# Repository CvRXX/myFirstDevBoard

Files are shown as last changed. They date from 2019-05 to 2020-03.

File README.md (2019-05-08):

# My first devboard

This devboard is meant to teach computer engineering students of the university of applied sciences to solder and to give them a learning platform to learn embeddded C++. This project is open source and can be found on github: github.com/CvRXX/myFirstDevBoard

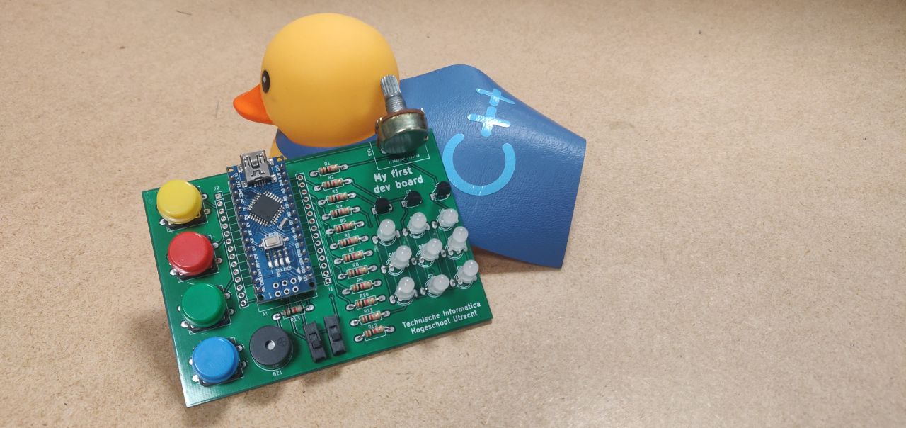
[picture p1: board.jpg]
The board


## What do you need?
To solder the board you need the following components:

    - The board (I ordered this at jlcpcb.com)
    - 13x 1kΩ resistors
    - 9x RGB LEDS (common annode)
    - 1x arduino nano with pinstrips (optionaly a female strip)
    - 1x passive buzzer
    - 4x push buttons
    - 2x slider switches (2.54mm pin distance)
    - 3x bc550 transistors 
    - 1x 1k pot meter (everything up to 10kΩ)
    - 1x usb cable for the nano
    
## How to solder it?
This readme is not a soldering course so the exact details on how to solder something should be found somewhere else. But I want to give some hints to make your life easier:

    1. Solder the components which are the lowest first (the resistors) and the highest last (the pod meter).
    2. Make sure you put in the leds the right way (long lead in the square hole).
    3. Put headers under the arduino nano so you can use the arduino for others things.
    4. Put the nano with headers on the board and then solder everything in one go.
    
## How to program it?
The one thing that I hate most about of the arduino nano is that they lack a bootloader. The students from Utrecht are lucky beause Florian and I flashed every board already. If you don't have such a nice person nearby you should flash it yourself. This tuturial describes it nicely: https://www.instructables.com/id/How-To-Burn-a-Bootloader-to-Clone-Arduino-Nano-30/.

After that you can use the arduino IDE to flash the board. The students from Utrecht are required to use bmptk & hwlib. 

To find out what is connected to what please read the schematic that's included. You can open this with the free opensource program called kicad (http://kicad-pcb.org/).

## I still run into problems, what now?
If you are a student from Utrecht you can go into the turing lab and ask Carlos, Florian or Wouter. If Utrecht is a bit far away from you feel free to email me : myfirstdevboard {at} carlosvanrooijen.nl

## I'm a teacher at an university and I really want to use this, can I?
Sure, love to see my board being used in other places. The only thing that I ask of you is that you retain my name on the board and send me an email that you use it. I only ask for the email because it makes me happy to know that others use it.

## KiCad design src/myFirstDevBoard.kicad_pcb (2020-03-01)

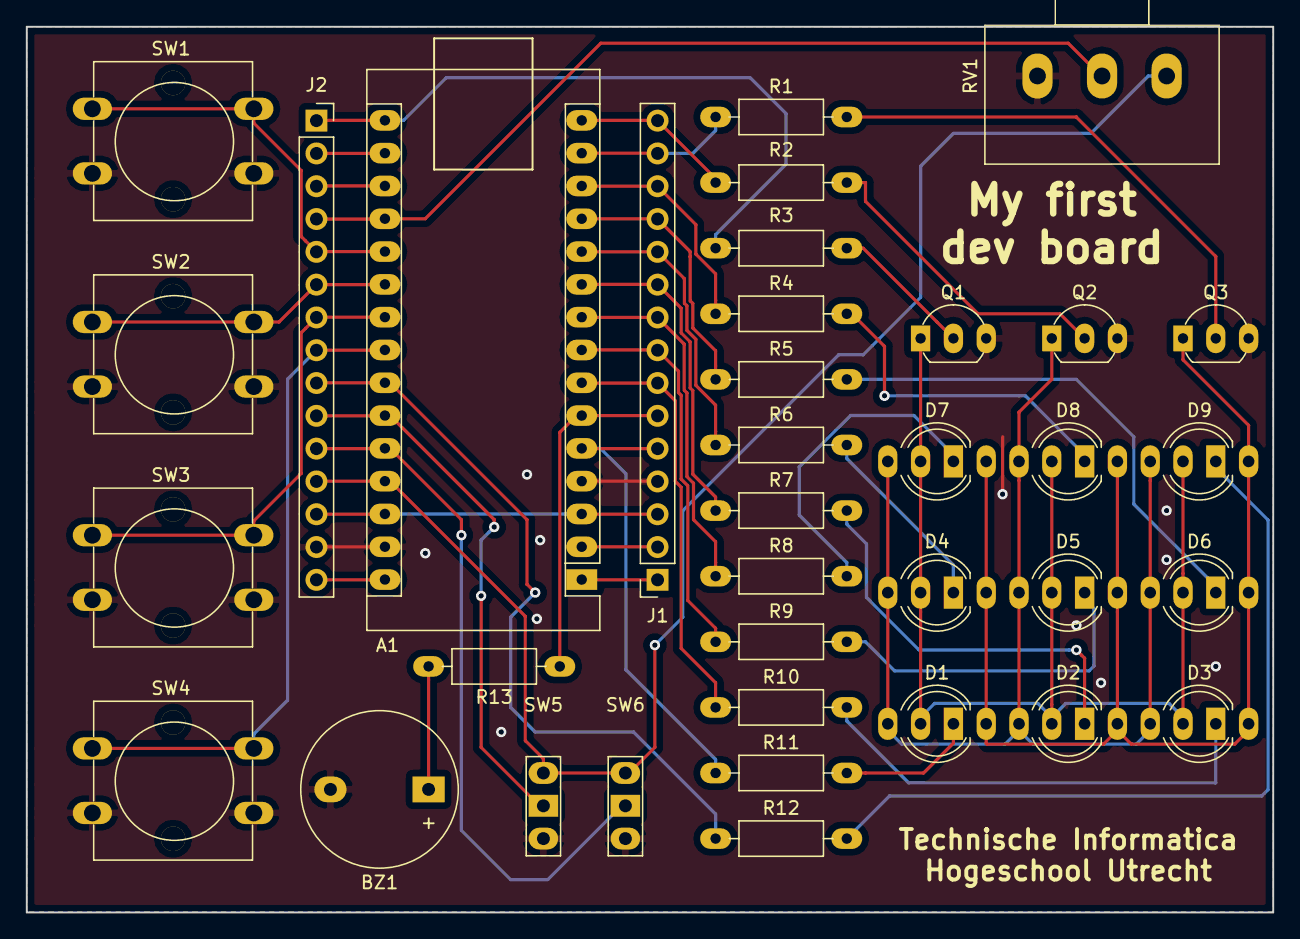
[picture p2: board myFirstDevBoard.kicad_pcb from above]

Board: 2 copper layers, 96.5 x 68.6 mm, 36 parts (0 on the bottom side), 44 nets.

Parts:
A1: Arduino_Nano_v3.x; Arduino_Nano_oval
BZ1: Buzzer; Buzzer_12x9.5RM7.6_oval
D1, D2, D3, D4, D5, D6, D7, D8, D9: LED_BGRA; LED_D5.0mm-4_RGB_wide
J1, J2: Conn_01x15_Male; PinSocket_1x15_P2.54mm_Vertical
Q1, Q2, Q3: BC550; TO-92_Inline_Wide_oval
R1, R2, R3, R4, R5, R6, R7, R8, R9, R10, R11, R12: 1kΩ; R_Axial_DIN0207_L6.3mm_D2.5mm_P10.16mm_Horizontal_oval
R13: R; R_Axial_DIN0207_L6.3mm_D2.5mm_P10.16mm_Horizontal_oval
RV1: R_POT; Potentiometer_Alps_RK163_Single_Horizontal_oval
SW1, SW2, SW3, SW4: SW_Push; SW_PUSH-12mm_with_poles
SW5, SW6: SW_SLIDER; PinHeader_1x03_P2.54mm_Vertical_oval

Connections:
+3V3: A1.17, J2.2
+5V: A1.27, J2.12, RV1.1, SW5.1, SW6.1
/aref: A1.18, J2.3
/blue: A1.14, J1.14, R1.1
/buzzer: A1.6, J1.6, R13.1
/green: A1.15, J1.15, R2.2
/led1: A1.5, J1.5, R11.1
/led2: A1.7, J1.7, R10.1
/led3: A1.8, J1.8, R9.1
/led4: A1.9, J1.9, R8.1
/led5: A1.10, J1.10, R7.1
/led6: A1.11, J1.11, R6.1
/led7: A1.12, J1.12, R5.1
/led8: A1.13, J1.13, R4.1
/led9: A1.24, J2.9, R12.1
/pot: A1.19, J2.4, RV1.2
/red: A1.16, J2.1, R3.2
/reset: A1.3, A1.28, J1.3, J2.13
/rx: A1.2, J1.2
/sw1: A1.20, J2.5, SW1.1
/sw2: A1.21, J2.6, SW2.1
/sw3: A1.22, J2.7, SW3.1
/sw4: A1.23, J2.8, SW4.1
/sw5: A1.26, J2.11, SW6.2
/sw6: A1.25, J2.10, SW5.2
/tx: A1.1, J1.1
/vin: A1.30, J2.15
GND: A1.4, A1.29, BZ1.2, J1.4, J2.14, Q1.3, Q2.3, Q3.3, RV1.3, SW1.2, SW2.2, SW3.2, SW4.2, SW5.3, SW6.3
unnamed: BZ1.1, R13.2
unnamed: D1.1, D2.1, D3.1, D4.1, D5.1, D6.1, D7.1, D8.1, D9.1, Q1.1
unnamed: D1.2, D2.2, D3.2, D4.2, D5.2, D6.2, D7.2, D8.2, D9.2, Q2.1
unnamed: D1.3, D2.3, D3.3, D4.3, D5.3, D6.3, D7.3, D8.3, D9.3, Q3.1
unnamed: D1.4, R11.2
unnamed: D2.4, R7.2
unnamed: D3.4, R10.2
unnamed: D4.4, R6.2
unnamed: D5.4, R9.2
unnamed: D6.4, R5.2
unnamed: D7.4, R8.2
unnamed: D8.4, R4.2
unnamed: D9.4, R12.2
unnamed: Q1.2, R3.1
unnamed: Q2.2, R2.1
unnamed: Q3.2, R1.2

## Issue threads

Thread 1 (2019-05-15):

The led print is the wrong way around.

CvRXX, 2019-05-15:
The square hole is oke but the led print is wrong.

CvRXX, 2020-03-01:
fixed with 051e06d5c5773110e520aa6cda6d3166771ad9fe

Closed 2020-03-01.

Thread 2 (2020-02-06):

room for m3 / rubber feet

wovo, 2020-02-06:

CvRXX, 2020-03-01:
@wovo I need the dimensions for the rubber feet to change this. Can you put them on your desk tomorrow so I can take a few to measure them?

CvRXX, 2020-03-03:
fixed by 696723d42228766d8a1a20b6e9d58cdf75adf79a

CvRXX, 2020-03-03:
Reopened because the board is now to big for fabrication at the desired price range. We have to expend in vertical direction.

CvRXX, 2020-03-03:
fixed with 70c8829129f8e52414bd638379cbc0dba544efa1

Closed 2020-03-03.

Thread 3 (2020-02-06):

silk component designator for switches (s1, sw2)

wovo, 2020-02-06:

CvRXX, 2020-03-01:
fixed by da5840e24c7d1efb5b0910834335d766e84f4e3d

Closed 2020-03-01.

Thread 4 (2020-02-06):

github url op onderkant

wovo, 2020-02-06:

CvRXX, 2020-03-01:
Waiting to fix this until I know how much space #2 is gonna free up.

CvRXX, 2020-03-03:
fixed by 696723d42228766d8a1a20b6e9d58cdf75adf79a

CvRXX, 2020-03-03:
Reopened because the board is now to big for fabrication at the desired price range. We have to expend in vertical direction.

CvRXX, 2020-03-03:
fixed with 70c8829129f8e52414bd638379cbc0dba544efa1

Closed 2020-03-03.

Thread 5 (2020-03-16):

RV silkscreen overlaps with Q3 sikscreen

CvRXX, 2020-03-16:
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

CvRXX, 2020-04-14:
fixed by dcb5ca5e1b2a036e74864194e843b40ed0e1ad16

Closed 2020-04-14.

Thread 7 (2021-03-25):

wire too close to LED solder pads

wovo, 2021-03-25:
The two 'jumping' wire segment between the 'created by' (solder side silk) and the nearest LEDs is too close to the LED solder pads. There is aple room to make a detour :)

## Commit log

2019-03-05 making v0.2
    [myFirstDevBoard.kicad_pcb, myFirstDevBoard.sch]
2019-03-20 adding v0.03
    [myFirstDevBoard.kicad_pcb, myFirstDevBoard.sch]
2019-03-28 changing silkscreen to be organised
    [myFirstDevBoard.kicad_pcb, myFirstDevBoard.sch]
2019-03-28 correcting colors
    [myFirstDevBoard.sch]
2019-03-28 reorganising schematic
    [myFirstDevBoard.sch]
2019-03-28 fixing layout and fixing comments
    [myFirstDevBoard.sch]
2019-03-28 fixing silkscreen
    [myFirstDevBoard.kicad_pcb]
2019-03-28 adding buzzer resistor
    [myFirstDevBoard.sch]
2019-03-28 updating version number
    [myFirstDevBoard.kicad_pcb]
2019-05-08 prepping for schematic deployment
    [myFirstDevBoard.sch]
2020-03-01 changing led silk to right orientation
    [myFirstDevBoard.kicad_pcb]
2020-03-01 moving switch designators up so they are visable above the switches closes #3
    [myFirstDevBoard.kicad_pcb]
2020-03-03 adding link and rubber feet fixing #4 fixing #2
    [myFirstDevBoard.kicad_pcb]
2020-03-03 Revert "adding link and rubber feet" This is reverted because the board is now to big for fab
    This reverts commit 696723d42228766d8a1a20b6e9d58cdf75adf79a.
    [myFirstDevBoard.kicad_pcb]
2020-03-03 adding rubber feet with mounting holes, github link and logso
